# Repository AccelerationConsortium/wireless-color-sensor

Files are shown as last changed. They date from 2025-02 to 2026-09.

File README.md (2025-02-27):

## Wireless Color Sensor

This is a tool for direct use with an OT-2 liquid handler, which allows for sampling a discrete light spectrum (8 wavelengths) at various wellplate positions. The tool is wireless both in power and data transfer.

The documentation for this project including a full set of build instructions is hosted at [GitHub Pages](https://AccelerationConsortium.github.io/wireless-color-sensor/).

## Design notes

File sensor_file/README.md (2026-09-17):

## This directory contains the files stored on the LCM demo sensor Pico W.

## File Structure Overview

This directory contains both development/test scripts and the core files required to run the LCM demo on the Pico W color sensor package.

### Test Scripts
- `as7341_LED.py`  
- `as7341_test.py`  
These two scripts are intended for development and testing purposes only. They were used during the prototyping phase to verify individual hardware components.

### Core Demo Files
- `main.py`  
  This is the main execution script that runs on the Pico W. It coordinates wireless communication, sensor readings, and response handling for the demo.
  
- `my_secrets.py.example`  
  Template for the local Wi-Fi credentials and other sensitive configuration variables required for network access.

  Copy it to `my_secrets.py`, fill in the local values, and keep that file untracked. It is excluded by the repository's `.gitignore`.
  
- `lib/`  
  This directory contains supporting libraries and modules required by `main.py`. It typically includes drivers and utility functions for handling hardware interactions and network communication.

Only `main.py`, a locally configured `my_secrets.py`, and the contents of the `lib/` folder are necessary for running the actual LCM demo. The test files can be removed or ignored in a production setup.

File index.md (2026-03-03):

# Getting started guide for wireless color sensor

## Overview 

This documentation provides a guide to assemble and test a color sensor package with a dual wireless charging port that could be implemented to the OT-2 liquid handling robot. 

   <div style="text-align: center; margin-top: 10px;">
      
  </div>

<br>
Following is a video of liquid color matching demo run on OT-2 with this wireless color sensor:

<div style="text-align: center; margin-top: 10px;">
  <iframe width="560" height="315"
          src="https://www.youtube.com/embed/Ql7_V_8dtdw?rel=0"
          title="YouTube video player"
          frameborder="0"
          allow="accelerometer; autoplay; clipboard-write; encrypted-media; gyroscope; picture-in-picture; web-share"
          allowfullscreen>
  </iframe>
</div>

<br>

Watch this [introduction video](https://www.youtube.com/watch?v=9EcxYCiEJx0) to learn more about the [LCM Hugging Face Space](https://huggingface.co/spaces/AccelerationConsortium/OT-2-LCM) used for liquid color matching experiments with the OT2 liquid handler and this wireless color sensor.

The estimated time of the hardware assembling is **3-4 hours** assuming no soldering background and low coding experience.

<br>

## Prerequisites

This documentation assumes that readers have completed [Course 1: Hello World](https://ac-microcourses.readthedocs.io/en/latest/courses/hello-world/index.html#) and possess basic knowledge of electronic soldering and wiring techniques.
<br>

## Bill of materials

### Electronic parts: 

  - **Sensor Package:**

    <div style="float: right; margin-left: 10px; width: 500px;">
      
    </div>

    - [<span class="color-red">① PicoW</span>](https://www.digikey.com/en/products/detail/raspberry-pi/SC0919/18713315)
    - [<span class="color-blue">② Pico LipoSHIM</span>](https://www.digikey.com/en/products/detail/pimoroni-ltd/PIM557/15851380)
    - [<span class="color-magenta">③ AS7341 color sensor</span>](https://www.digikey.com/en/products/detail/adafruit-industries-llc/4698/13162109)
    - [<span class="color-orange">④ Picowbell P5905</span>](https://www.digikey.com/en/products/detail/adafruit-industries-llc/5905/22596390)
    - [<span class="color-purple">⑤ STEMMA QT Wire</span>](https://www.digikey.com/en/products/detail/sparkfun-electronics/PRT-17258/13629029)
    - [<span class="color-green">⑥ Wireless charger receiver</span>](https://www.digikey.ca/en/products/detail/adafruit-industries-llc/1901/5629432)

    - [<span class="color-yellow">⑦ Lipo battery with 2-pole JST connector wire</span>](https://www.amazon.ca/EEMB-Battery-Rechargeable-Lithium-Connector/dp/B08FD3V6TF/)

    - [<span class="color-cyan">⑧ 1 Pin male connector jumper wires (2x)</span>](https://www.digikey.ca/en/products/detail/adafruit-industries-llc/4482/11594500)

   <br style="clear: both;"> 

  - **Wireless charging port (Dual charging):**

    <div style="float: right; margin-left: 10px; width: 500px;">
      
    </div>

    - [<span class="color-red">① Wireless charger transmitters (2x) </span>](https://www.digikey.ca/en/products/detail/adafruit-industries-llc/2162/6827104)
    - <span class="color-orange"> ② Mirco-USB to USB Type-A cables ([1 short](https://www.amazon.ca/gp/product/B073PQWY2B/) and [1 long](https://www.digikey.ca/en/products/detail/stewart-connector/SC-2AMK003F/8544577)) </span>
    - [<span class="color-blue">③ Power supply (5V 2A) </span>](https://www.digikey.ca/en/products/detail/xp-power/VEL05US050-US-BB/5023710)
   
    <br style="clear: both;"> 

:::{Note}
 **Qi wireless charging:**
 The wireless charging modules linked above comply with the [Qi standard](https://en.wikipedia.org/wiki/Qi_(standard)), providing a consistent power output of 5V/500mA within an effective distance of 2-8mm. However, they are relatively more expensive.
:::

:::{Note}
 **Alternative:**
 One lower-cost alternative is [this inductive charging set](https://www.adafruit.com/product/1459), which requires a 9V power supply. Note that its output is less efficient and inconsistent, varying based on the power input and charging distance. Additionally, it lacks electromagnetic shielding and USB ports, which may require more advanced electronic knowledge to configure.
:::

### 3D printed parts: 

  - **Sensor package:**

     <div style="float: right; margin-left: 10px; width: 500px;">
      
     </div>

    - <span class="color-red">① Microcontroller backboard</span>
    - <span class="color-orange">② Sensor stand</span>
    - <span class="color-blue">③ Sensor package main enclosure</span>
    
    <br style="clear: both;"> 

  <br>

  - **Wireless charging port:** 

     <div style="float: right; margin-left: 10px; width: 500px;">
      
     </div>

    - <span class="color-red">① Enclosure A side</span>
    - <span class="color-orange">② Enclosure B side</span>
    - <span class="color-blue">③ Base board</span>
    - <span class="color-magenta">④ Transmitter supports (2x) </span>

    <br style="clear: both;"> 

  All the 3D printing files can be found in [this link](https://github.com/Neil-YL/wireless-color-sensor/tree/07829dd6418d59315a7711e57d3ba6ff898b8a76/CAD-File/STEP). If your 3D printer is Bambu Lab series, [project files](https://github.com/Neil-YL/wireless-color-sensor/tree/c080448a7fcbc0e26ace216282e9614ede66aa17/CAD-File/BamBu-File) are available for BambuStudio.

:::{Hint}
Print the sensor package and the charging port enclosure with light-color material so that the LED indicators could be visible from the outsides.
:::

### Mechanical components and tools: 

  - **Mechanical components:**

     <div style="float: right; margin-left: 10px; width: 500px;">
      
     </div>

    - <span class="color-red">① M2.5-10mm screws (4x)</span>
    - <span class="color-orange">② M2.5 hex nuts (4x)</span>
    - <span class="color-blue">③ Painter's tape</span>

    <br style="clear: both;"> 

 <br>

  - **Tools required:**

     <div style="float: right; margin-left: 10px; width: 500px;">
      
     </div>

    - <span class="color-red">① Phillips-head #0 screwdriver</span>
    - <span class="color-blue">② Soldering set</span>

  <br style="clear: both;"> 

 <br>

  - **Tools nice to have:**

     <div style="float: right; margin-left: 10px; width: 500px;">
      
     </div>

    - <span class="color-red">① Tools to remove 3D printing supports and deburr surface</span>
    - <span class="color-blue">② Multimeter for electronic connection troubleshooting</span>

  <br style="clear: both;"> 
 
## Hardware assembly

  ### Preparation / Before you begin assembling: 

  #### 3D printed parts preparation:

   Remove all printing supports from the 3D-printed parts. Deburr all the supported surfaces and edges, especially following highlighted areas that will be used for assembly.

  :::{hint}
  <span style="padding-left: 10px;">Use wirecutters to remove most of the supports from the printed parts.</span>  
  <span style="padding-left: 10px;">Clean up remaining spikes with sharp utility knives or scissors.</span>
  :::

   - <span class="color-red">inner walls of the sensor package</span> and <span class="color-orange">those of the charging port enclosure A/B</span>

  <div style="text-align: center; margin-top: 10px;">
    
  </div>

  <br>

   - <span class="color-blue">sliding slots</span> on the sensor enclosure and <span class="color-blue">tips</span> on the controller backboard.

  <div style="text-align: center; margin-top: 10px;">
    
  </div>

 <br>

   You may also test the fit between the sensor enclosure and the pipette on the OT-2. Polish as needed until it achieves a similar fit shown in the photo.

  <div style="text-align: center; margin-top: 10px;">
    
  </div>

   <br>

  #### Electronic parts soldering:
   
  1. **LipoSHIM:** 

     Place the LipoSHIM on the back of the PicoW, ensure <span class="color-red">the power button</span> of the LipoSHIM and <span class="color-blue">the micro-USB port</span> on the PicoW are on the same side. Position the LipoSHIM close to the USB port end of the PicoW pins, not at the far end, so that the Picowbell can be mounted later.

     <div style="text-align: center; margin-top: 10px;">
       
     </div>

     <br>
     
     Solder <span class="color-orange">8 pins on each row</span> on the PicoW.

     <div style="text-align: center; margin-top: 10px;">
       
     </div>
     
     <br>

     You may connect the PicoW to a micro-USB power supply and use the power button to check the soldering connection; <span class="color-red">the white LED indicator</span> on the LipoSHIM should light up.
     
     <div style="text-align: center; margin-top: 10px;">
       
     </div>

  <br>

  2. **Battery connnector:**
     
     If you are working with the battery from the link provided in BOM section or if <span class="color-blue">the polarity of your battery</span> 2-pin JST connector is opposite to <span class="color-red">that of the LipoSHIM</span>:

     <div style="text-align: center; margin-top: 10px;">
       
     </div>

     :::{warning}
      Never connect your battery to PicoSHIM with wrong polarity!
     :::

     You can correct it by cutting off the connector, swapping the wires, and then resoldering them to match the correct polarity.

     <div style="text-align: center; margin-top: 10px;">
       
     </div>

<br>

  3. **Wireless charging unit:** 

     Solder a jumper wire to <span class="color-red">the C1+ (or C2+) pad</span> and another to <span class="color-blue">the GND pad</span> on the receiver board.

     <div style="text-align: center; margin-top: 10px;">
       
     </div>     

     <div style="text-align: center; margin-top: 10px;">
       
     </div>   

     <br>

     Connect the transmitter to a power supply via micro-USB port and place the receiver on top of the transmitter (coils faced with coils). Check if <span class="color-blue">the blue LED charging indicator</span> on the transmitter board lights up. You may use a multimeter to measure the voltage between the two jumper wires; the reading should be approximately 5V.

     <div style="text-align: center; margin-top: 10px;">
       
     </div>      

  #### Dual charging connection check:

   You may also check the connection of the dual wireless charging setup before start assembling. Use the short micro-USB/USB Type-A cable to connect two transmitters and connect the transmitter that has a free micro-USB port to a power supply. Test the receiver with the same procedure above for the wireless charging unit, the receiver should give a voltage reading of approximately 5V on each transmitter.

   <div style="text-align: center; margin-top: 10px;">
      
   </div>      
  
  <br>
      
  ### Assembling:

  #### Sensor Package assembling:

  1. **Connect battery to Picow and LipoSHIM assembly:**
  
      Ensure the polarity of the battery matches the +/- markings on the LipoSHIM, if you are using the battery from the link provided in BOM section, [reverse the polarity](battery-connector) before connecting it to the LipoSHIM. 
     
     :::{warning}
       Never connect your battery to PicoSHIM with wrong polarity!
     :::

      Connect the battery to the LipoSHIM with <span class="color-blue">the JST connector</span>. Adjust the wires of the battery to through <span class="color-red">a row of pins</span> on the PicoW. 

     <div style="text-align: center; margin-top: 10px;">
       
     </div>   
    
     <br>

      Test connection: Press the button on the LipoSHIM to power on the PicoW; <span class="color-blue">the white LED indicator</span> on the LipoSHIM should light up. Connect the PicoW to a power supply via the micro-USB port; <span class="color-red">the red LED charging indicator</span> on the LipoSHIM should also light up. 

     <div style="text-align: center; margin-top: 10px;">
       
     </div>   

     <br>

      Power off and disconnect the power supply before proceeding with following steps.

  2. **Mount PicoW on Picowbell:** 
  
      Place the PicoW on the top of the Picowbell sockets; <span class="color-red">the micro-USB port</span> on PicoW should be at the same side as <span class="color-blue">the STEMMA QT port</span> on Picowbell.  

      <div style="text-align: center; margin-top: 10px;">
       
     </div>   

     <br>     

     Carefully align the pins and press down the PicoW to secure it onto the Picowbell.

   :::{hint}  
   Since the power button on the PicoSHIM will interfere with the STEMMA QT port on the Picowbell, you don’t need to push the PicoW all the way down.
   :::

  3. **Connect wireless charging receiver to Picowbell:**
  
      Connect the GND jumper wire from the receiver to <span class="color-red">the GND socket</span> (third on the right, No.38) on the Picowbell. 
      
      Connect the C1+(or C2+) jumper wire to <span class="color-blue">the VBUS socket</span> (first on the right, No.40) on the Picowbell. 
      
      <div style="text-align: center; margin-top: 10px;">
       
     </div>  

     <br> 

      Place the receiver on the powered transmitter, <span class="color-red">the red LED indicator</span> on LipoSHIM and <span class="color-blue">the blue LED indicator</span> on the transmitter should light up.

     <div style="text-align: center; margin-top: 10px;">
       
     </div>   

     <br> 
 
  4. **Connect AS7341 to Picowbell:**

      Connect <span class="color-red">AS7341</span> to <span class="color-blue">Picowbell's STEMMA QT port</span> with a STEMMA QT wire. 

     <div style="text-align: center; margin-top: 10px;">
       
     </div>   

     <br>       
      Turn on the Picow (using the button on LipoSHIM), <span class="color-green">the green LED indicator</span> on AS7341 should light on.

     <div style="text-align: center; margin-top: 10px;">
       
     </div>   

     <br>   

      Test the color sensor (software testing section)

  5. **Assemble Picowbell to the backboard:** 

      Align the assemble holes on Picowbell to those on the backboard, ensuring that <span class="color-red">the micro-USB port</span> on Picow is positioned on the side of <span class="color-blue">the backboard's opening slot</span>, adjusting the sensor cable to <span class="color-orange">one side within the case</span>. 

     <div style="text-align: center; margin-top: 10px;">
       
     </div>   

     <br>   
      
      Insert <span class="color-red">the screws</span> through the holes on the Picowbell, position the nuts from <span class="color-blue">the back of the backboard</span>, and secure them with a screwdriver.

     <div style="text-align: center; margin-top: 10px;">
       
     </div> 

      :::{Hint}
      The positions of the nuts and screws can be swapped, but this method is generally easier for assembly.
      :::

  6. **Secure sensor stand to the main enclosure end:**
  
      The sensor stand is a thin board with four spikes, designed with a thinner edge and a thicker edge. Position the sensor stand with <span class="color-red">the thinner edge</span> at the opening side of the main enclosure and the spikes on the top. 
      
      <div style="text-align: center; margin-top: 10px;">
       
     </div>   

     <br>   
      
      Insert it into the sensor end of the main enclosure. If the sensor stand is properly assembled, the spikes will be slightly higher than the surrounding flat surface.

      <div style="text-align: center; margin-top: 10px;">
       
     </div>   

     <br>   

  7. **Secure the color sensor to the stand:** 
  
      Face down the AS7341, with <span class="color-red">the yellow square</span> on AS7341 close to opening of the main enclosure, align the assemble holes with four spikes, secure AS7341 to the stand.

     <div style="text-align: center; margin-top: 10px;">
       
     </div>   

     <br>   
  
     <div style="text-align: center; margin-top: 10px;">
       
     </div>   

     <br>   

      The yellow square on AS7341 should be visible from the hole of the sensor enclosure if the sensor is assembled properly.
    
     <div style="text-align: center; margin-top: 10px;">
       
     </div>   

     <br>   

:::{Note}
 If you would like to disassemble the sensor or sensor stand after assembly, use a tweezer(or a similar tool) to gently pry up one side of the sensor, then the other side, gradually lifting it out from four spikes. For the sensor stand, use a thin tool to push it up from the bottom. Be careful not to touch the central electronic components of the sensor during this process.
:::

  8. **Secure the receiver:**

     Prepare two pieces of painter’s tape, approximately 40mm long each. Place the wireless charger receiver on the inner wall of the enclosure, with the coils facing against the wall and the receiver board on the right, and secure with the painter's tape. 

     <div style="text-align: center; margin-top: 10px;">
       
     </div>   

     <br>   

  9. **Final Assembly of the Backboard and Main Enclosure：**

     Aligning the sliding tips on both ends of the backboard to the sliding slots on the main enclosure, adjusting all the wires within the enclosure, carefully assemble the backboard to the main enclosure. 
    
     <div style="text-align: center; margin-top: 10px; display: flex; justify-content: center;">
      
      
     </div>

     <br>   

:::{Note}
  **Video Guide**:
   You may also refer to this video for step-by-step assembly guide
:::

 <div style="text-align: center; margin-top: 10px;">
      <iframe width="560" height="315" src="https://www.youtube.com/embed/9jREn-jBnCQ?list=PLY8jlH96_zN2E55mRGohK9wP5QhzqMF7C&rel=0" 
              title="YouTube video player" 
              frameborder="0" 
              allow="accelerometer; autoplay; clipboard-write; encrypted-media; gyroscope; picture-in-picture; web-share" 
              allowfullscreen>
      </iframe>
 </div>

  <br>  

  **🎉 Congrats, your wireless color sensor is ready to go!**
    
   <div style="text-align: center; margin-top: 10px;">
       
   </div>   

   <br>  

  #### Dual Charging port assembling:

  1. Join the A and B sides of the charging port enclosure, aligning them properly, and secure both parts together.

     <div style="text-align: center; margin-top: 10px;">
       
     </div>   

     <br>  

  2. Plug the short micro-USB cable into <span class="color-red">the micro-USB port</span> on one transmitter.

     <div style="text-align: center; margin-top: 10px;">
       
     </div>   

     <br>  

     Place the transmitter onto the transmitter support with the coils facing outward. 

     <div style="text-align: center; margin-top: 10px;">
       
     </div>   

     <br>

     Route the coils wires down from <span class="color-blue">the thinner edge</span> of the support. 

     <div style="text-align: center; margin-top: 10px;">
       
     </div>   

     <br>
     
     Insert the transmitter support with transmitter board into the port enclosure assembly. Then, secure it in place, ensuring there is no gap between the transmitter coils and the wall of the sensor slot.

     <div style="text-align: center; margin-top: 10px;">
       
     </div>   

     <br>

:::{Hint}
 If there is a gap between the coils and the inner wall, or if the transmitter support bends significantly, consider polishing the walls for assembling to achieve a better fit.
:::

  3. Thread the long micro-USB cable through the square hole into the charging port assembly with the micro-USB head.

     <div style="text-align: center; margin-top: 10px;">
       
     </div>   

     <br>

  4. Place another transmitter on the transmitter support with the coils facing outward. 
  
     <div style="text-align: center; margin-top: 10px;">
       
     </div>   

     <br>  

     Route the coils wires down from the thicker side of the support through <span class="color-blue">the routing slot</span>. 

     <div style="text-align: center; margin-top: 10px;">
       
     </div>   

     <br>  

     Insert the transmitter support into the port enclosure assembly, leaving the transmitter board on the top. Secure the transmitter support in place, ensuring there is no gap between the transmitter coils and the wall of the sensor slot.

     <div style="text-align: center; margin-top: 10px;">
       
     </div>   

     <br>  

  5. Connect the short USB cable to the USB type-A port on the second transmitter. Connect the long micro-USB cable to the micro-USB port of the second transmitter. If you find any difficulties with cable connections, try swapping two transmitters to rearrange cable.

     <div style="text-align: center; margin-top: 10px;">
       
     </div>   

     <br>  
        
  6. Connect the long cable to a power supply. The LED indicators on both transmitters should flash in the following sequence: blue; red; blue and red, and all off. If either indcator does not flash, you may check the cable connections.

     <div style="text-align: center; margin-top: 10px;">
       
     </div>   

     <br>  

  7. Arrange the cables inside the enclosure and assemble the base board to the port enclosure. Place the sensor package on the slot of the charging port, the red indicator on the sensor package should light up.

     <div style="text-align: center; margin-top: 10px; display: flex; justify-content: center;">
      
      
     </div>

     <br>   

:::{Note}
  **Video Guide**:
   You may also refer to this video for step-by-step assembly guide
:::

 <div style="text-align: center; margin-top: 10px;">
      <iframe width="560" height="315" src="https://www.youtube.com/embed/p-gA2RxMddI?list=PLY8jlH96_zN2E55mRGohK9wP5QhzqMF7C&rel=0" 
              title="YouTube video player" 
              frameborder="0" 
              allow="accelerometer; autoplay; clipboard-write; encrypted-media; gyroscope; picture-in-picture; web-share" 
              allowfullscreen>
      </iframe>
 </div>

  <br>  
  
## Software part

### Test code for sensor
   Before closing the enclosure, you may run the test code for the sensor. Turn on the PicoW, connect it to your PC and follow the setup instructions for Thonny and MicroPython for your Pico W and the AS7341 library file, in [Course 1: Hello World](https://ac-microcourses.readthedocs.io/en/latest/courses/hello-world/index.html#).

   Save the following codes as "as7341_test.py" and upload it to your PicoW. 
    
```python
      import time
      from machine import I2C, Pin
      from as7341_sensor import Sensor

      # Initialize the AS7341 sensor
      sensor = Sensor(i2c=I2C(0, scl=Pin(5), sda=Pin(4)))

      def read_sensor_data():
          """Read dictionary of sensor data"""
          # Get all channel data from the sensor
          channel_data = sensor.all_channels

          CHANNEL_NAMES = [
              "ch410",
              "ch440",
              "ch470",
              "ch510",
              "ch550",
              "ch583",
              "ch620",
              "ch670",
          ]

          # Return a dictionary that maps channel names to sensor data
          return dict(zip(CHANNEL_NAMES, channel_data))

      print("Testing sensor...")
      sensor_data = read_sensor_data()
      print(sensor_data)

      def test_sensor():
          """Interactive testing interface for the AS7341 sensor."""
          print("AS7341 Sensor Test")
          print("==================")
          print("Type 'read' to sample data or 'exit' to quit.")

          while True:
              # Wait for a command from the user
              command = input("Command: ").strip().lower()

              if command == "read":
                  # Ask whether to turn on the LED
                  led_choice = input("Turn on LED for this reading? (yes/no): ").strip().lower()
                  if led_choice == "yes":
                      sensor.LED = True  # Turn on LED
                      print("LED is ON.")

                  # Trigger sensor data reading
                  sensor_data = read_sensor_data()
                  if sensor_data:
                      print("Sensor Data:")
                      for wavelength, value in sensor_data.items():
                          #print(f"{wavelength}: {value}")
                          print(f"{value}")
                  else:
                      print("Failed to read sensor data.")

                  # Turn off the LED if it was turned on
                  if led_choice == "yes":
                      sensor.LED = False  # Turn off LED
                      print("LED is OFF.")

              elif command == "exit":
                  print("Exiting the program.")
                  break
              else:
                  print("Invalid command. Type 'read' to sample or 'exit' to quit.")

      # Directly call the test_sensor function
      test_sensor()
```  
 
Run this script on your Pico W. It should return results as follows; the data for each channel may vary depending on what your color sensor is detecting.

```  
    MPY: soft reboot
    Detected devices at I2C-addresses: 0x39
    Testing sensor...
    {'ch583': 1507, 'ch670': 775, 'ch510': 756, 'ch410': 99, 'ch620': 1548, 'ch470': 344, 'ch550': 1172, 'ch440': 294}
    AS7341 Sensor Test
    ==================
    Type 'read' to sample data or 'exit' to quit.
    Command: 
```   
  
You use command "Read" to start a measurement, and "Yes/No" to control the LED lighting on the color sensor.

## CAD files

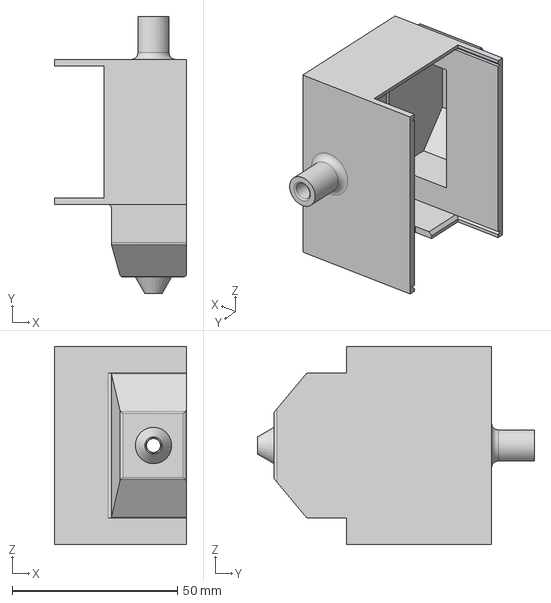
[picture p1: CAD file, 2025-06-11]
CAD-File/STEP/Sensor package main enclosure.step
40.0 x 84.0 x 60.0 mm

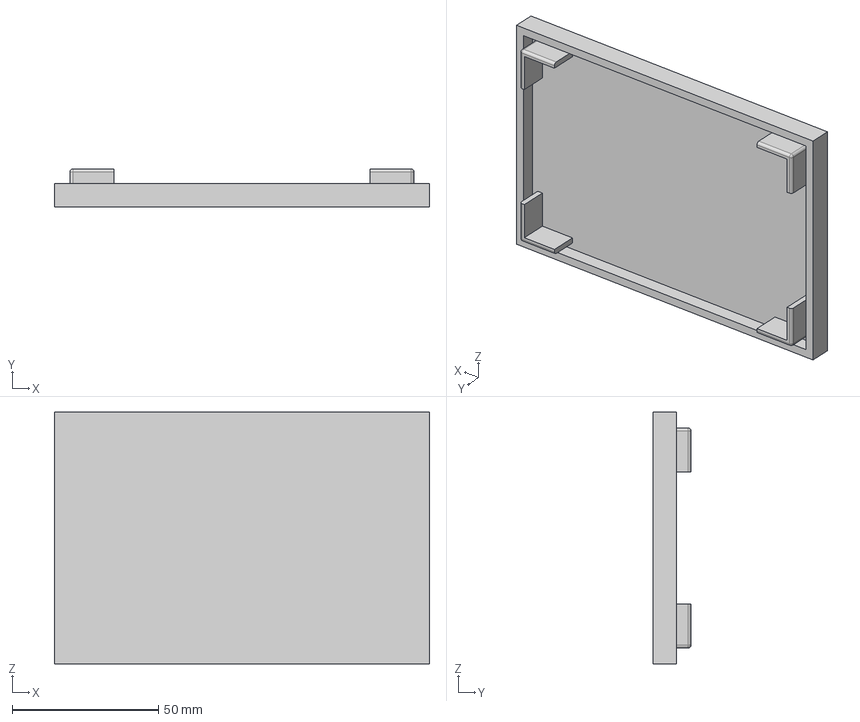
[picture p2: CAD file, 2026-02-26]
CAD-File/STEP/Charging Base.step
128.0 x 13.0 x 86.0 mm

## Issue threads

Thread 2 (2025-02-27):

Feedback

sgbaird, 2025-02-27:
I wanted to say again, well done! The instructions are clear and easy to parse through. The color coding works well I think - for example when it says "screws" and then it shows where those screws go. It keeps things pretty clean. The figures were effective, and there was a tight correlation between text and images.

The videos adds an extra layer of help for random bits that might be confusing for some (e.g., like inserting the 4-prong piece).

The structure of the CAD files as well as the inclusion of the Bambu project file and linking back to them make it easier for people to find and streamline things I think.

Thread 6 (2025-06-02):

Add yt embedded video at top of index page

sgbaird, 2025-06-02:
```html
<iframe width="560" height="315" src="https://www.youtube.com/embed/Ql7_V_8dtdw?si=1xcwbXNmUfm3K2xs" title="YouTube video player" frameborder="0" allow="accelerometer; autoplay; clipboard-write; encrypted-media; gyroscope; picture-in-picture; web-share" referrerpolicy="strict-origin-when-cross-origin" allowfullscreen></iframe>
```

Could also link to https://youtu.be/9EcxYCiEJx0?si=aq3iU75M-o05p63D

Neil-YL, 2025-06-04:
Added.

Closed 2025-06-04.

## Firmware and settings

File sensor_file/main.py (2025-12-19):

import sys
import json
import ssl
import asyncio
import ntptime
from uio import StringIO
from time import time, sleep

from machine import I2C, Pin

# WiFi
from netman import connectWiFi

# Hardware
import machine
from neopixel import NeoPixel
from as7341_sensor import Sensor

# MQTT
from mqtt_as import MQTTClient, config

from my_secrets import (
    SSID,
    PASSWORD,
    HIVEMQ_HOST,
    HIVEMQ_PASSWORD,
    HIVEMQ_USERNAME,
    COURSE_ID,
    PICO_ID,
)


def get_onboard_led():
    try:
        onboard_led = Pin("LED", Pin.OUT)  # only works for Pico W
    except Exception as e:
        print(e)
        onboard_led = Pin(25, Pin.OUT)
    return onboard_led

onboard_led = get_onboard_led()


def sign_of_life(led, first, blink_interval_ms=5000):
    global last_blink
    if first:
        led.on()
        last_blink = ticks_ms()
    time_since = ticks_diff(ticks_ms(), last_blink)
    if led.value() == 0 and time_since >= blink_interval_ms:
        led.toggle()
        last_blink = ticks_ms()
    elif led.value() == 1 and time_since >= 500:
        led.toggle()
        last_blink = ticks_ms()


# Instantiate the Sensor class
sensor = Sensor(i2c = I2C(0, scl=Pin(5), sda=Pin(4)))


def read_sensor_data():
    """Read dictionary of sensor data"""
   # sensor.LED = True

    # Get all channel data from the sensor
    channel_data = sensor.all_channels
  #  sensor.LED = False

    CHANNEL_NAMES = [
        "ch410",
        "ch440",
        "ch470",
        "ch510",
        "ch550",
        "ch583",
        "ch620",
        "ch670",
    ]

    # Return a dictionary that maps channel names to sensor data
    return dict(zip(CHANNEL_NAMES, channel_data))


print("Testing sensor...")
sensor_data = read_sensor_data()
print(sensor_data)


# Description: Receive commands from HiveMQ and send dummy sensor data to HiveMQ

connectWiFi(SSID, PASSWORD, country="CA")

# To validate certificates, a valid time is required
ntptime.timeout = 5  # type: ignore
ntptime.host = "time.google.com"
try:
    ntptime.settime()
except Exception as e:
    print(f"{e} with {ntptime.host}. Trying again after 5 seconds")
    sleep(5)
    try:
        ntptime.settime()
    except Exception as e:
        print(f"{e} with {ntptime.host}. Trying again with pool.ntp.org")
        sleep(5)
        ntptime.host = "pool.ntp.org"
        ntptime.settime()

print("Obtaining CA Certificate from file")
with open("hivemq-com-chain.der", "rb") as f:
    cacert = f.read()
f.close()

# Local configuration
config.update(
    {
        "ssid": SSID,
        "wifi_pw": PASSWORD,
        "server": HIVEMQ_HOST,
        "user": HIVEMQ_USERNAME,
        "password": HIVEMQ_PASSWORD,
        "ssl": True,
        "ssl_params": {
            "server_side": False,
            "key": None,
            "cert": None,
            "cert_reqs": ssl.CERT_REQUIRED,
            "cadata": cacert,
            "server_hostname": HIVEMQ_HOST,
        },
        "keepalive": 15,
    }
)


# Dummy function for running a color experiment
def run_color_experiment(R, Y, B):

    # set_color(R, Y, B)
    sensor_data = read_sensor_data()
    print(sensor_data)
    # clear_color()

    return sensor_data


# MQTT Topics, not used in LCM
command_topic = f"{COURSE_ID}/request"

# my_id = hexlify(machine.unique_id()).decode()

# MQTT Topics
command_topic = f"command/picow/{PICO_ID}/as7341/read"
sensor_data_topic = f"color-mixing/picow/{PICO_ID}/as7341"

print(f"Command topic: {command_topic}")
print(f"Sensor data topic: {sensor_data_topic}")

async def messages(client):  # Respond to incoming messages
    async for topic, msg, retained in client.queue:
        try:
            topic = topic.decode()
            msg = msg.decode()
            retained = str(retained)
            print((topic, msg, retained))

            if topic == command_topic:
                # Parse the incoming message as JSON
                incoming_dict = json.loads(msg)
                command = incoming_dict["command"]
                experiment_id = incoming_dict["experiment_id"]

                # Extract the RGB values and experiment_id from the command
                R = command["R"]
                Y = command["Y"]
                B = command["B"]
                

                # Run the color experiment with the specified RGB values
                sensor_data = run_color_experiment(R, Y, B)

                # Combine the sensor data with the original command
                payload_data = incoming_dict.copy()
                payload_data.update({"sensor_data": sensor_data})
                #payload_data["course_id"] = COURSE_ID

                # Convert the payload data to a JSON string
                payload = json.dumps(payload_data)

                # Publish the payload to the sensor data topic
                await client.publish(sensor_data_topic, payload)
                print("sensor results published")

        except Exception as e:
            with StringIO() as f:  # type: ignore
                sys.print_exception(e, f)  # type: ignore
                print(f.getvalue())  # type: ignore


async def up(client):  # Respond to connectivity being (re)established
    while True:
        await client.up.wait()  # Wait on an Event
        client.up.clear()
        await client.subscribe(command_topic, 1)  # renew subscriptions


async def main(client):
    await client.connect()
    for coroutine in (up, messages):
        asyncio.create_task(coroutine(client))

    start_time = time()
    # must have the while True loop to keep the program running
    while True:
        await asyncio.sleep(5)
        onboard_led.toggle()
        elapsed_time = round(time() - start_time)
        print(f"Elapsed: {elapsed_time}s")


config["queue_len"] = 5  # Use event interface with specified queue length
MQTTClient.DEBUG = True  # Optional: print diagnostic messages
client = MQTTClient(config)
try:
    asyncio.run(main(client))
finally:
    client.close()  # Prevent LmacRxBlk:1 errors

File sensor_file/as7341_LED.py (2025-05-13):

import time
from machine import I2C, Pin
from as7341_sensor import Sensor

# Initialize the AS7341 sensor
sensor = Sensor(i2c=I2C(0, scl=Pin(5), sda=Pin(4)))

try:
    while True:
        # Turn on the LED
        sensor.LED = True
        print("LED is ON.")
        time.sleep(3)  # Keep LED on for 3 seconds

        # Turn off the LED
        sensor.LED = False
        print("LED is OFF.")
        time.sleep(3)  # Keep LED off for 3 seconds

except KeyboardInterrupt:
    # Handle manual interruption gracefully
    print("\nProgram interrupted by user.")

finally:
    # Ensure LED is off before exiting
    if sensor.LED:
        print("Turning off the LED before exiting.")
        sensor.LED = False
    print("Program terminated.")

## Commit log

2025-05-13 Create README.md
    Create directory to store file on the sensor.
2025-05-14 Update as7341_test.py
    remove LED on in read()
2025-06-04 Update index.md with correct link in BOM
2025-06-11 Update new design
    [Sensor package main enclosure.step]
2025-11-24 Add minimal Colab test notebook for wireless color sensor
2025-11-26 Replace mqtt_as with umqtt.simple for better wifi stability
    [main.py]
2025-11-26 Fix code review issues: add missing imports, improve error handling
    [main.py]
2025-11-26 Remove unused experiment_id variable and fix on_connect callback signature
    [main.py]
2025-11-26 Fix MQTT timing: increase keepalive to 3600s, remove blocking sleep from main loop
    [main.py]
2025-12-17 Revert to mqtt_as.py from umqtt.simple for better reliability
    [main.py]
2025-12-19 Revert back to 575dbdcf
    original mqtt_as implementation
    [main.py]
2026-02-26 Replacing step file with the correct one
    [Charging Base.step]
2026-02-26 Clarify LipoSHIM positioning in soldering instructions
    Add note that LipoSHIM should be positioned close to the USB port end
    of the PicoW pins so the Picowbell can be mounted later.
2026-03-03 Update links for wireless charger components (had been swapped)
2026-09-17 Remove tracked sensor credentials
